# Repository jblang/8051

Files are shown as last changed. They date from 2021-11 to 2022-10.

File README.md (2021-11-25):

# 8051 Board for RC2014

This is a board design for an 8051 (specifically, for the Maxim DS80C320). I had the board manufactured but initial bringup was not successful, and I have not had time to debug it.  I am posting on GitHub as a backup in case I ever get back to it, or in case anyone else wants to take it further.

## License

Copyright 2021 J.B. Langston

Permission is hereby granted, free of charge, to any person obtaining a copy of this software and associated documentation files (the "Software"), to deal in the Software without restriction, including without limitation the rights to use, copy, modify, merge, publish, distribute, sublicense, and/or sell copies of the Software, and to permit persons to whom the Software is furnished to do so, subject to the following conditions:

The above copyright notice and this permission notice shall be included in all copies or substantial portions of the Software.

THE SOFTWARE IS PROVIDED "AS IS", WITHOUT WARRANTY OF ANY KIND, EXPRESS OR IMPLIED, INCLUDING BUT NOT LIMITED TO THE WARRANTIES OF MERCHANTABILITY, FITNESS FOR A PARTICULAR PURPOSE AND NONINFRINGEMENT. IN NO EVENT SHALL THE AUTHORS OR COPYRIGHT HOLDERS BE LIABLE FOR ANY CLAIM, DAMAGES OR OTHER LIABILITY, WHETHER IN AN ACTION OF CONTRACT, TORT OR OTHERWISE, ARISING FROM, OUT OF OR IN CONNECTION WITH THE SOFTWARE OR THE USE OR OTHER DEALINGS IN THE SOFTWARE.

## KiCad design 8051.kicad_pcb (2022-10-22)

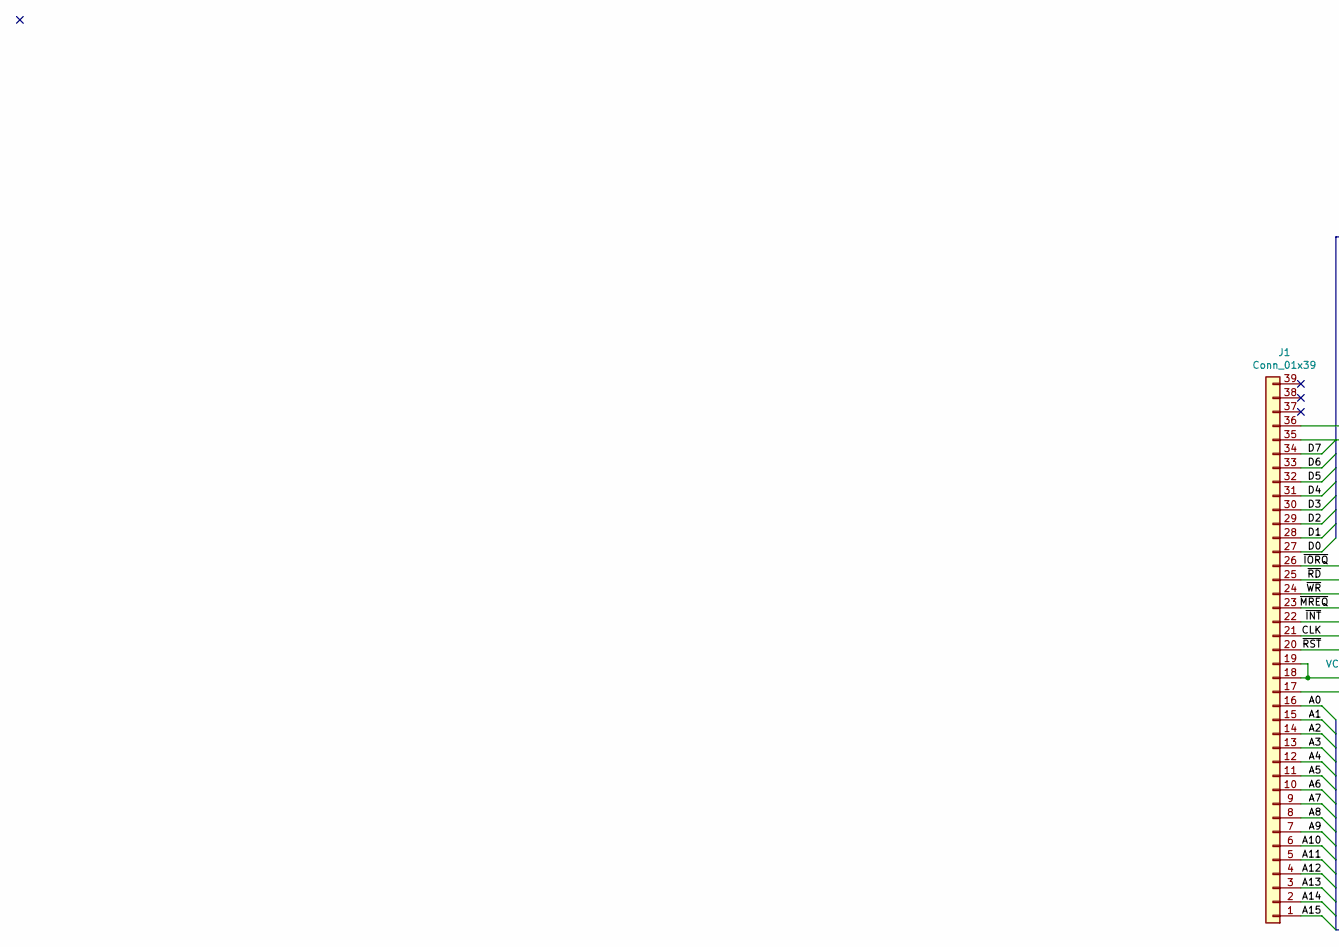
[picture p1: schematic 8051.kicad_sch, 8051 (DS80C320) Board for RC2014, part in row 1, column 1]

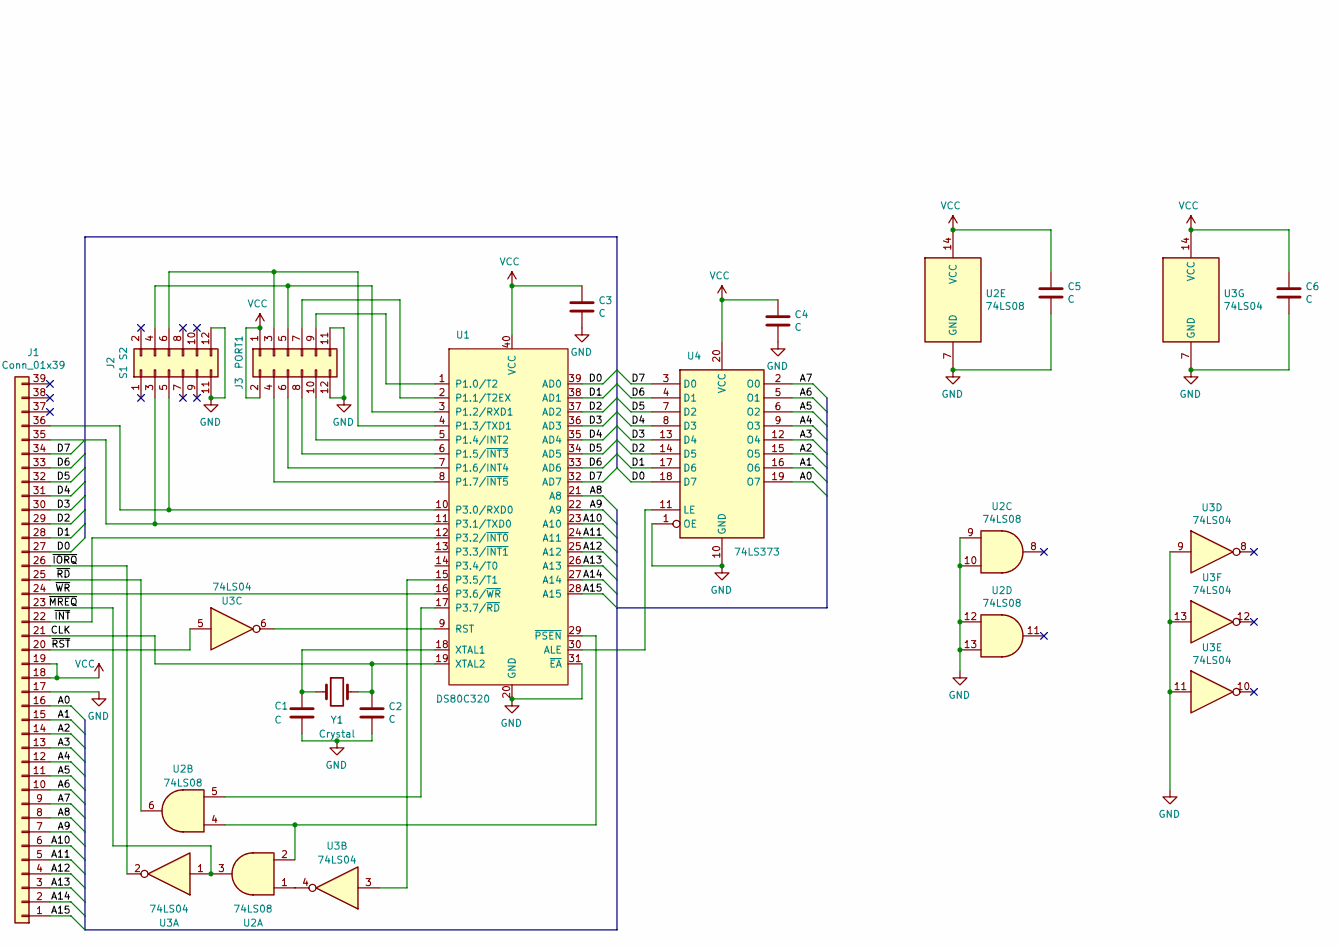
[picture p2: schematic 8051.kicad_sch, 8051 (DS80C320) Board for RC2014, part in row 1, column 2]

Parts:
C1, C2, C3, C4, C5, C6: C; C_Disc_D3.0mm_W1.6mm_P2.50mm
J1: Conn_01x39; PinHeader_1x39_P2.54mm_Vertical
J2: S1 S2; PinHeader_2x06_P2.54mm_Horizontal
J3: PORT1; PinSocket_2x06_P2.54mm_Vertical
U1: DS80C320; DIP-40_W15.24mm
U2: 74LS08; DIP-14_W7.62mm
U3: 74LS04; DIP-14_W7.62mm
U4: 74LS373; DIP-20_W7.62mm
Y1: Crystal; Crystal_HC49-4H_Vertical

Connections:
/A0: J1.16, U4.19 (O7)
/A1: J1.15, U4.16 (O6)
/A2: J1.14, U4.15 (O5)
/A3: J1.13, U4.12 (O4)
/A4: J1.12, U4.9 (O3)
/A5: J1.11, U4.6 (O2)
/A6: J1.10, U4.5 (O1)
/A7: J1.9, U4.2 (O0)
/A8: J1.8, U1.21 (A8)
/A9: J1.7, U1.22 (A9)
/A10: J1.6, U1.23 (A10)
/A11: J1.5, U1.24 (A11)
/A12: J1.4, U1.25 (A12)
/A13: J1.3, U1.26 (A13)
/A14: J1.2, U1.27 (A14)
/A15: J1.1, U1.28 (A15)
/CLK: C2.1, J1.21, U1.19 (XTAL2), Y1.2
/D0: J1.27, U1.39 (AD0), U4.18 (D7)
/D1: J1.28, U1.38 (AD1), U4.17 (D6)
/D2: J1.29, U1.37 (AD2), U4.14 (D5)
/D3: J1.30, U1.36 (AD3), U4.13 (D4)
/D4: J1.31, U1.35 (AD4), U4.8 (D3)
/D5: J1.32, U1.34 (AD5), U4.7 (D2)
/D6: J1.33, U1.33 (AD6), U4.4 (D1)
/D7: J1.34, U1.32 (AD7), U4.3 (D0)
/~INT: J1.22, U1.12 (P3.2/~INT0)
/~IORQ: J1.26, U3.2
/~MREQ: J1.23, U2.3, U3.1
/~RD: J1.25, U2.6
/~RST: J1.20, U3.5
/~WR: J1.24, U1.16 (P3.6/~WR)
GND: C1.2, C2.2, C3.2, C4.2, C5.2, C6.2, J1.17, J2.11, J2.12, J3.11, J3.12, U1.20 (GND), U1.31 (~EA), U2.7 (GND), U2.9, U2.10, U2.12, U2.13, U3.7 (GND), U3.9, U3.11, U3.13, U4.1 (OE), U4.10 (GND)
unnamed: C1.1, U1.18 (XTAL1), Y1.1
unnamed: J1.35, J2.3, U1.11 (P3.1/TXD0)
unnamed: J1.36, J2.5, U1.10 (P3.0/RXD0)
unnamed: J2.4, J3.5, U1.3 (P1.2/RXD1)
unnamed: J2.6, J3.3, U1.4 (P1.3/TXD1)
unnamed: J3.4, U1.8 (P1.7/~INT5)
unnamed: J3.6, U1.7 (P1.6/INT4)
unnamed: J3.7, U1.2 (P1.1/T2EX)
unnamed: J3.8, U1.6 (P1.5/~INT3)
unnamed: J3.9, U1.1 (P1.0/T2)
unnamed: J3.10, U1.5 (P1.4/INT2)
unnamed: U1.9 (RST), U3.6
unnamed: U1.15 (P3.5/T1), U3.3
unnamed: U1.17 (P3.7/~RD), U2.5
unnamed: U1.29 (~PSEN), U2.2, U2.4
unnamed: U1.30 (ALE), U4.11 (LE)
unnamed: U2.1, U3.4
VCC: C3.1, C4.1, C5.1, C6.1, J1.18, J1.19, J3.1, J3.2, U1.40 (VCC), U2.14 (VCC), U3.14 (VCC), U4.20 (VCC)

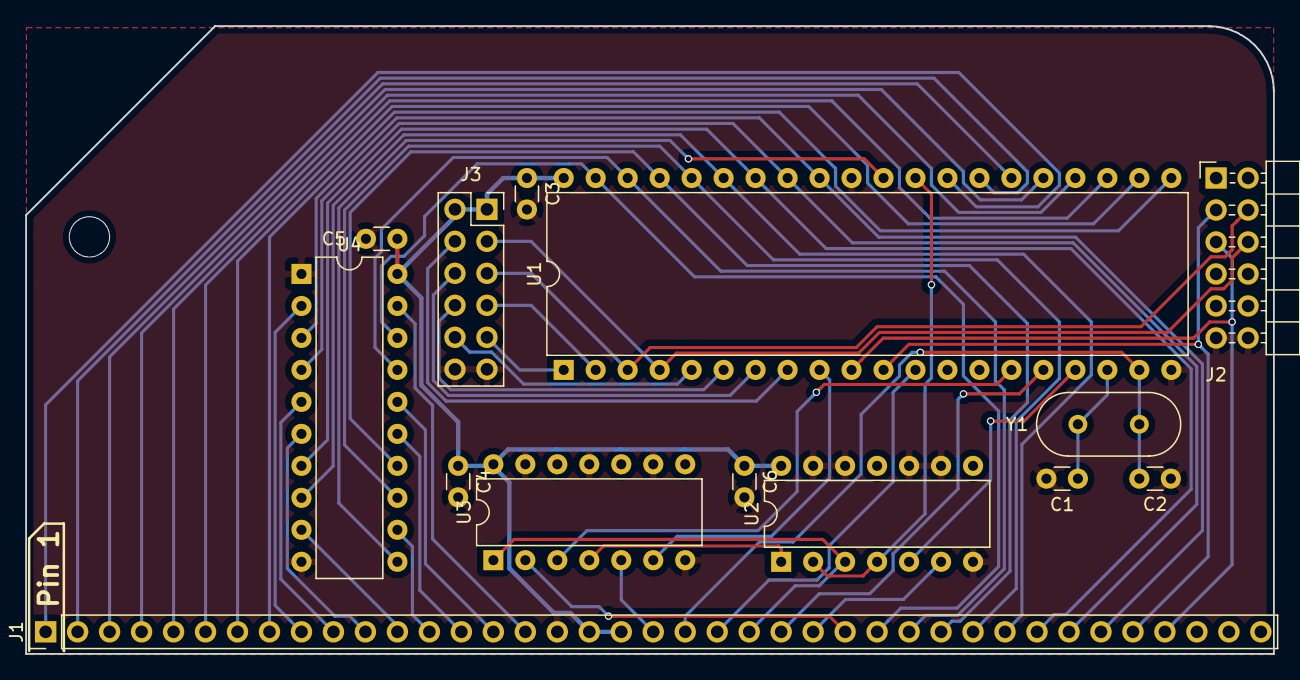
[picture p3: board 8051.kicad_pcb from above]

Board: 2 copper layers, 99.1 x 49.9 mm, 14 parts (0 on the bottom side), 50 nets.
